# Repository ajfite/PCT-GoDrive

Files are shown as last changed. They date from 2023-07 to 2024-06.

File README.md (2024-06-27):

# PC Transporter GoDrive

A clone of the original Applied Engineering Transdrive adapter that allows
you to connect an Apple II PC Transporter to a standard DOS Drive.

At this time it has only been tested with Gotek Floppy Emulators but it
should allow you to use any DOS PC Drive of the era.

## BOM

The DigiKey part number reflect my most recent order - you can substitute as you see fit.

| Schematic Part | Part | Total Quantity | Manufacturer Part Number | DigiKey Part Number | Notes |
|---|---|---|---|---|---|
| U1 | 74LS138/1 | 1 | TI SN74LS138N | 296-1639-5-ND | |
| U2 | 7407N | 1 | TI SN7407N | 296-1436-ND | |
| R1, R2, R3, R4 | 2.7K Resistor | 4 | Stackpole RSMF2JT2K70 | RSMF2JT2K70CT-ND | Any 2.7k commodity resistor will work, the pad is sized perfectly for the noted part but you definitely can use a smaller cheaper resistor. The large resistors where an aesthetic choice. |
| C1, C2 | 0.1uF Capacitor | 2 | Nichicon UKL1H0R1MDDANA  | 493-15375-ND | |
| J1, J2 | 34 position keyed header | Up to 2 | On Shore Tech 302-S341 | ED10528-ND | This connector is optional, depends on how you want to connect your floppy drive to the board |

Total BOM cost for parts only at time of purchasing (June 13, 2023) was $11.81.

Unfortunately the DB-19 connector for the Apple II interface is not easily sourced, so it is not included here.

## License



This work is licensed under a [Creative Commons Attribution-ShareAlike 4.0 International License](http://creativecommons.org/licenses/by-sa/4.0/).

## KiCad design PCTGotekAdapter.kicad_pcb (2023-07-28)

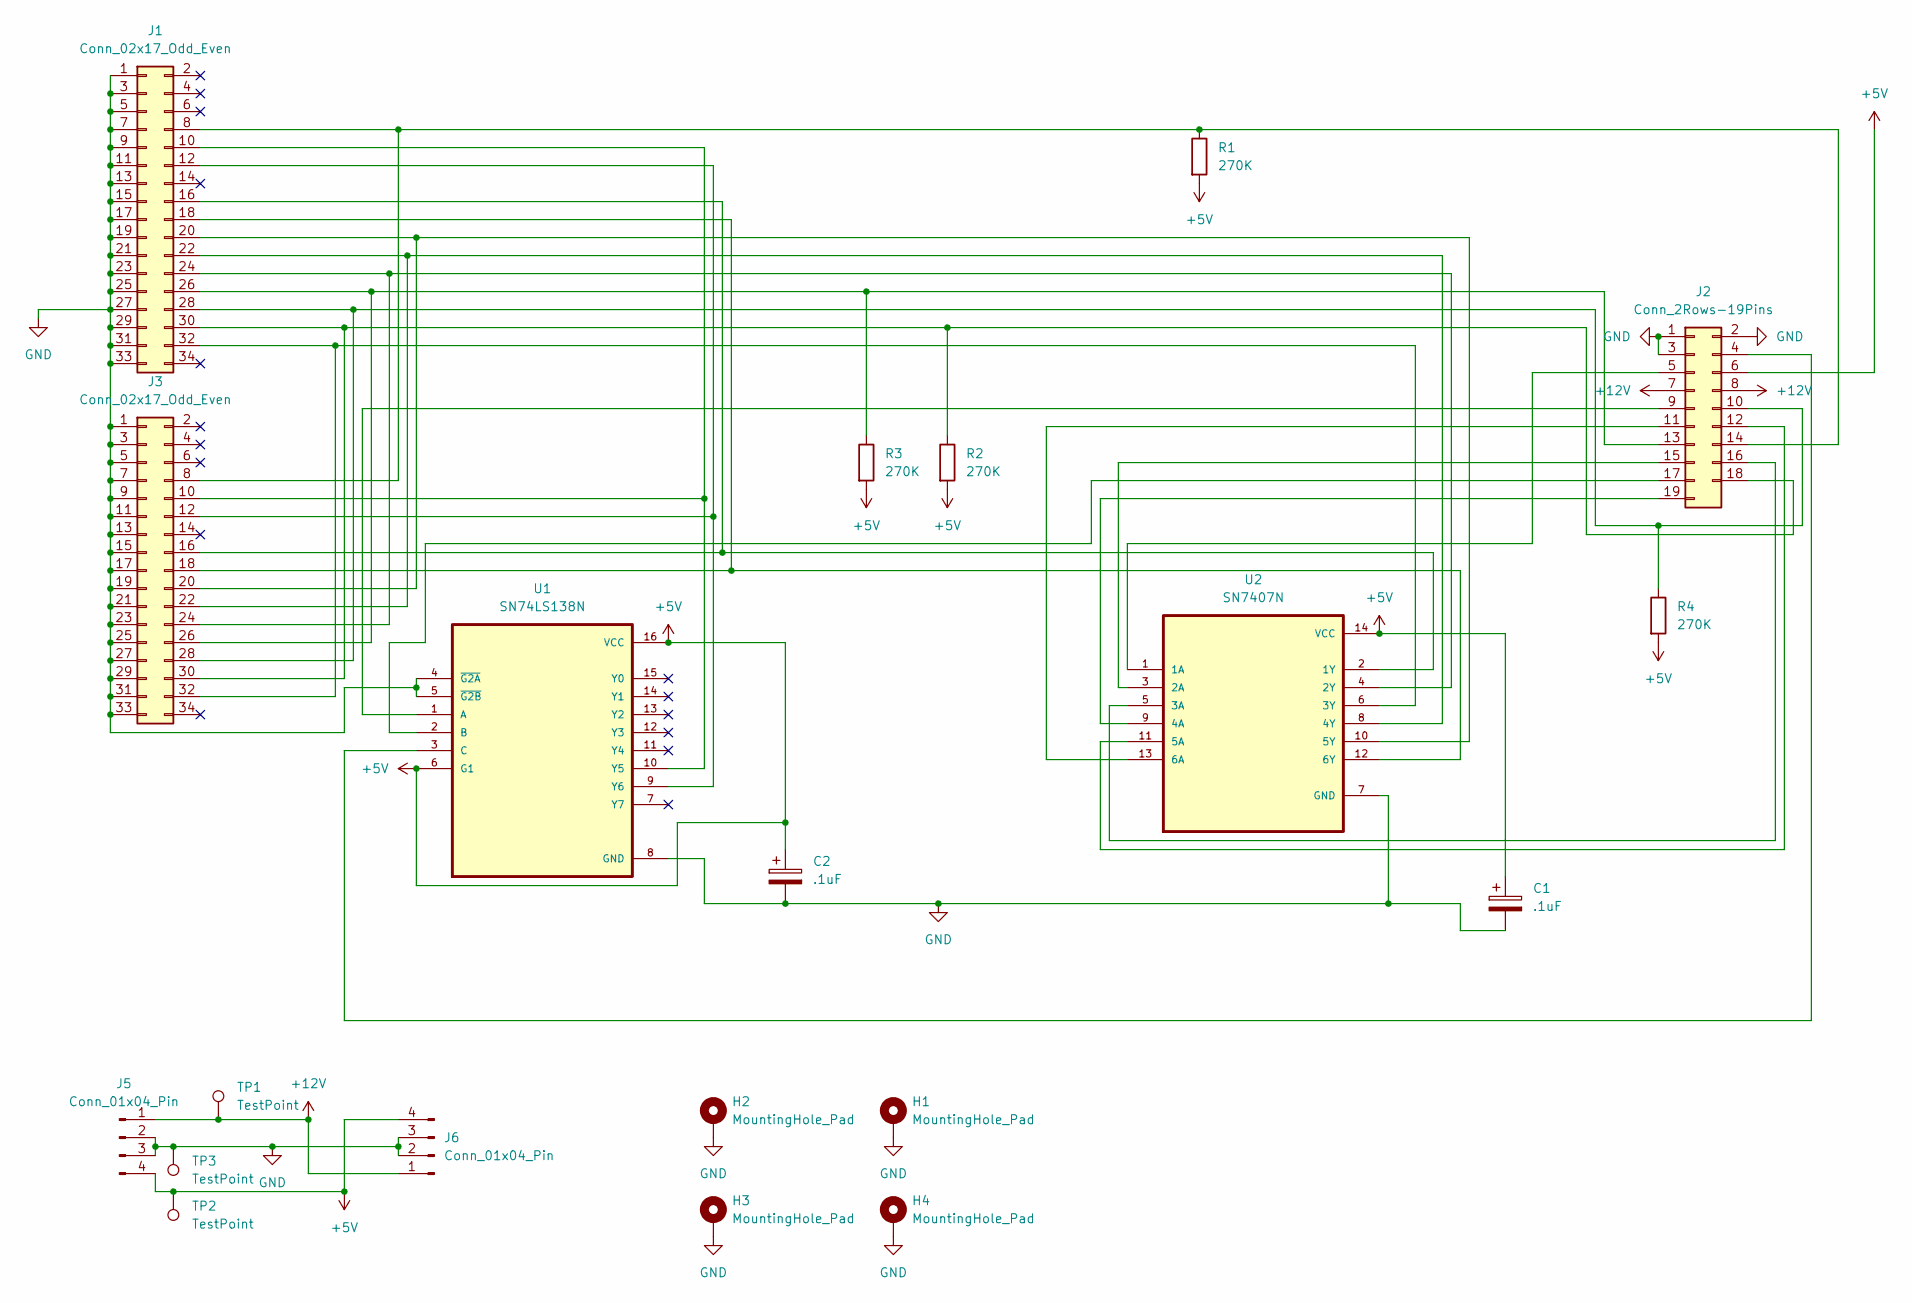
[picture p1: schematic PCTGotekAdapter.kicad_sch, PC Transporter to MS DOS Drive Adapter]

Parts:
C1, C2: .1uF; CP_Radial_D5.0mm_P2.00mm
H1, H2, H3, H4: MountingHole_Pad; MountingHole_3.2mm_M3_Pad_Via
J1, J3: Conn_02x17_Odd_Even; PinHeader_2x17_P2.54mm_Vertical
J2: Conn_2Rows-19Pins; PinHeader_2x10_P2.54mm_Vertical
J5, J6: Conn_01x04_Pin; PinSocket_1x04_P2.54mm_Vertical
R1, R2, R3, R4: 270K; R_Axial_DIN0414_L11.9mm_D4.5mm_P15.24mm_Horizontal
TP1, TP2, TP3: TestPoint; TestPoint_Pad_2.5x2.5mm
U1: SN74LS138N; DIP794W45P254L1969H508Q16
U2: SN7407N; DIP794W45P254L1969H508Q14

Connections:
+5V: C1.1, C2.1, J2.6, J5.4, J6.4, R1.2, R2.2, R3.2, R4.2, TP2.1, U1.6 (G1), U1.16 (VCC), U2.14 (VCC)
+12V: J2.7, J2.8, J5.1, J6.1, TP1.1
GND: C1.2, C2.2, H1.1, H2.1, H3.1, H4.1, J1.1, J1.3, J1.5, J1.7, J1.9, J1.11, J1.13, J1.15, J1.17, J1.19, J1.21, J1.23, J1.25, J1.27, J1.29, J1.31, J1.33, J2.1, J2.2, J2.3, J3.1, J3.3, J3.5, J3.7, J3.9, J3.11, J3.13, J3.15, J3.17, J3.19, J3.21, J3.23, J3.25, J3.27, J3.29, J3.31, J3.33, J5.2, J5.3, J6.2, J6.3, TP3.1, U1.4 (~G2A), U1.5 (~G2B), U1.8 (GND), U2.7 (GND)
unnamed: J1.8, J2.14, J3.8, R1.1
unnamed: J1.10, J3.10, U1.10 (Y5)
unnamed: J1.12, J3.12, U1.9 (Y6)
unnamed: J1.16, J3.16, U2.2 (1Y)
unnamed: J1.18, J3.18, U2.12 (6Y)
unnamed: J1.20, J3.20, U2.10 (5Y)
unnamed: J1.22, J3.22, U2.8 (4Y)
unnamed: J1.24, J3.24, U2.4 (2Y)
unnamed: J1.26, J2.13, J3.26, R3.1
unnamed: J1.28, J2.10, J3.28, R4.1
unnamed: J1.30, J2.18, J3.30, R2.1
unnamed: J1.32, J3.32, U2.6 (3Y)
unnamed: J2.4, U1.3 (C)
unnamed: J2.5, U2.1 (1A)
unnamed: J2.9, U1.1 (A)
unnamed: J2.11, U2.13 (6A)
unnamed: J2.12, U2.11 (5A)
unnamed: J2.15, U2.3 (2A)
unnamed: J2.16, U2.5 (3A)
unnamed: J2.17, U1.2 (B)
unnamed: J2.19, U2.9 (4A)

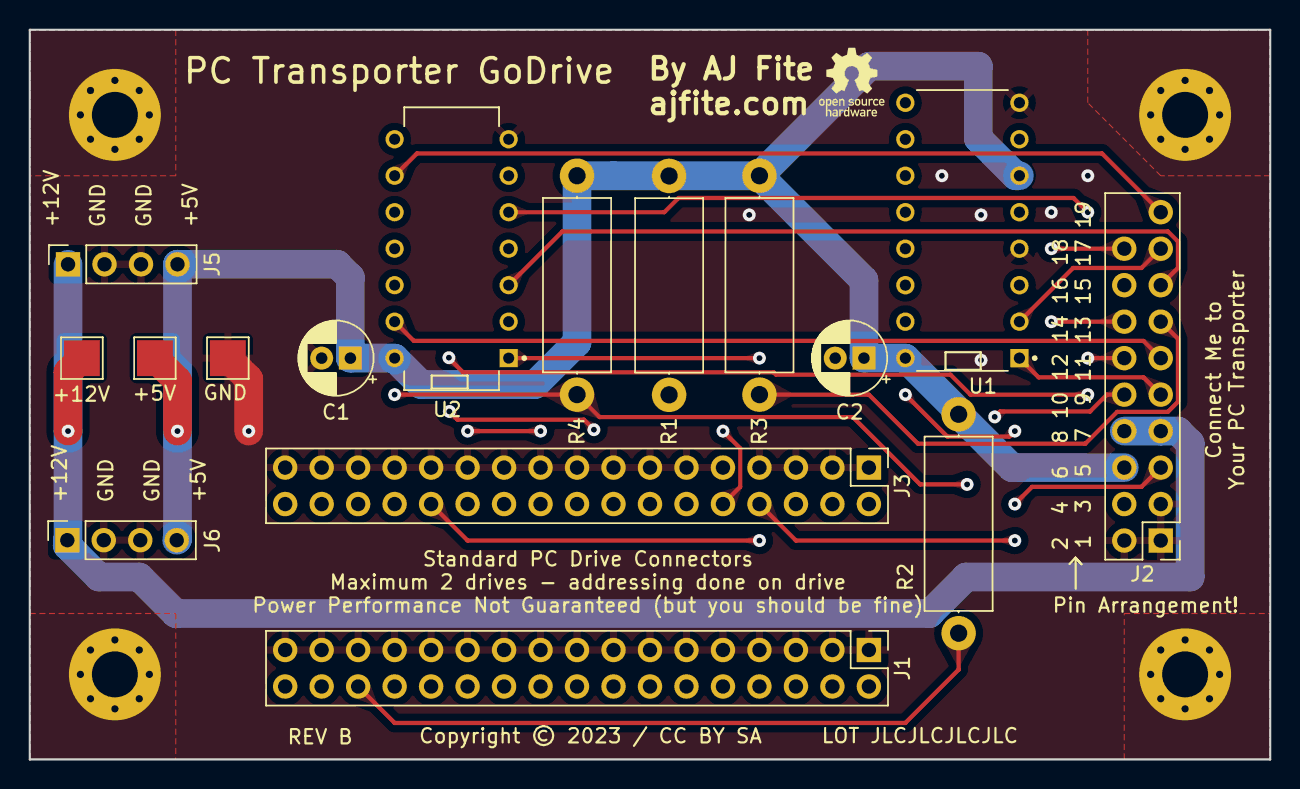
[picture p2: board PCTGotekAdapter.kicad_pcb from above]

Board: 4 copper layers, 86.4 x 50.8 mm, 20 parts (0 on the bottom side), 24 nets.

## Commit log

2023-06-06 REV A commit
    [PCTGotekAdapter-B_Cu.gbl, PCTGotekAdapter-B_Mask.gbs, PCTGotekAdapter-B_Paste.gbp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]
2023-06-22 First pass at REV B
    [PCTGotekAdapter.kicad_pcb]
2023-06-22 Remove extraneous connector from schematic
    Also some silkscreen and path tweaks
    [PCTGotekAdapter.kicad_pcb, PCTGotekAdapter.kicad_sch]
2023-07-15 Additional updates to the PCB and silk
    This will be ready for printing extremely soon
    [PCTGotekAdapter.kicad_pcb]
2023-07-28 Silkscreen and routing updates, schematic fixes
    Also ignored .zip files
    [PCTGotekAdapter.kicad_pcb, PCTGotekAdapter.kicad_sch]
2023-07-28 Changes to schematic info
    [PCTGotekAdapter.kicad_pcb, PCTGotekAdapter.kicad_sch]
2024-06-27 Correct an error on the schematic
    Resistors were listed as 270K, they should be 2.7K
    [PCTGotekAdapter.kicad_sch]
2024-06-27 Add the BOM to the README
2024-06-27 Ignore some garbage KiCAD makes
2024-06-27 Rev B production files
    [PCTGotekAdapter-B_Cu.gbl, PCTGotekAdapter-B_Mask.gbs, PCTGotekAdapter-B_Paste.gbp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]
2024-06-27 Adding more KiCAD autosave stuff

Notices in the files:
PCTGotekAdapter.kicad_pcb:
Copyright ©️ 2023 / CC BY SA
